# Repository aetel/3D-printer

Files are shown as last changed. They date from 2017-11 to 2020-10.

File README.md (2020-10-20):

Este repo contiene información, ficheros y archivos de configuración de las impresoras 3D de AETEL.  

# Federada
Nuestra Prusa i3 es un clon chino de la Prusa i3 MK2S.

# Genghis Khan
Prusa Mendel. [Clon 258 de Clone Wars](https://www.reprap.org/wiki/Clone_Wars:_El_imperio_de_los_clones/es#251-300). Piezas originales [entregadas por Obijuan](http://aetel.etsist.upm.es/2012/10/11/recogida-de-piezas-de-prusa-2-de-manos-de-obijuan/#more-1306).

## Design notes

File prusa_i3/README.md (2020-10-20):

# Federada
Federada es nuestra Prusa i3, un clon chino de la Prusa i3 MK2S.

Lleva dicho nombre en honor a Javier "Federado", gran impulsor de la impresión 3D y la filosofía RepRap dentro de la Asociación de Electrónica.

Algunas piezas han sido adaptadas para las vitaminas que se pueden conseguir en China. La electrónica es completamente distinta a la original de Prusa, SKR 1.3 de 32 bits; la cama caliente es la estándar RepRap.

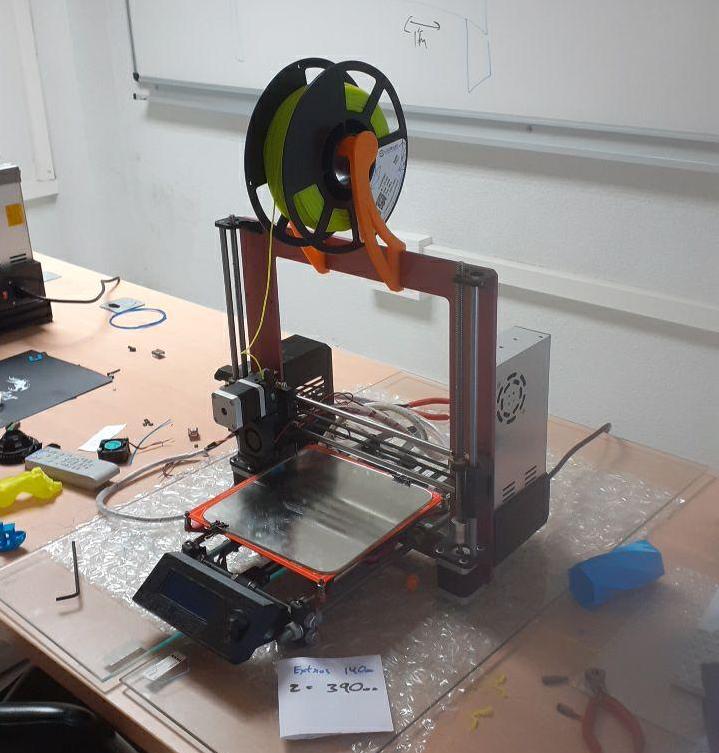
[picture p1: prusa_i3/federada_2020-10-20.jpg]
Federada


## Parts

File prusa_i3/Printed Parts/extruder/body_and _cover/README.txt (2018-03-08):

The 8mm sensor is approximately 21.5mm right and 9mm back from the nozzle.
The 12mm sensor is approximately 27mm right and 7mm back from the nozzle.
The 18mm sensor is approximately 32mm right and 3mm back from the nozzle.

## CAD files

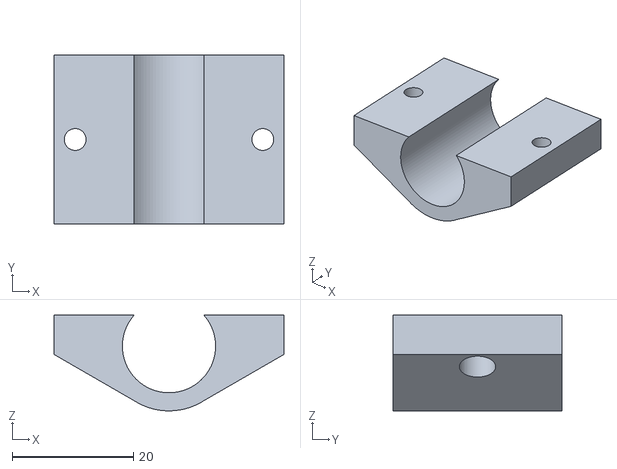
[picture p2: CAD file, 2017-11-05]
prusa_i3/Printed Parts/lmu88-holder-full.stl
38.0 x 27.9 x 15.8

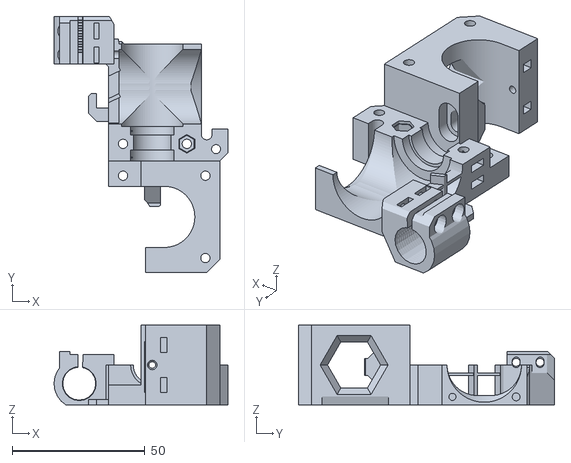
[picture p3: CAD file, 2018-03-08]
prusa_i3/Printed Parts/extruder/body_and _cover/extruder-bodyMK8S12.stl
65.5 x 96.5 x 30.0

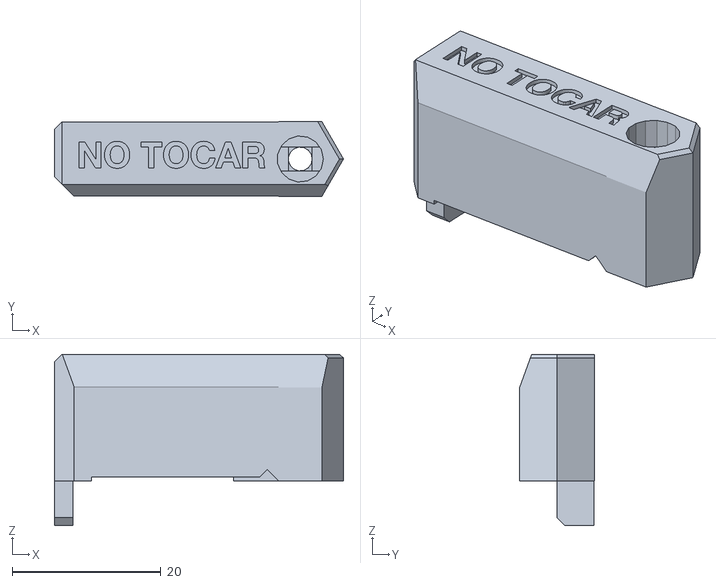
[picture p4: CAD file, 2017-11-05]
prusa_i3/Printed Parts/extruder/fan-nozzle.stl
38.8 x 10.0 x 23.0

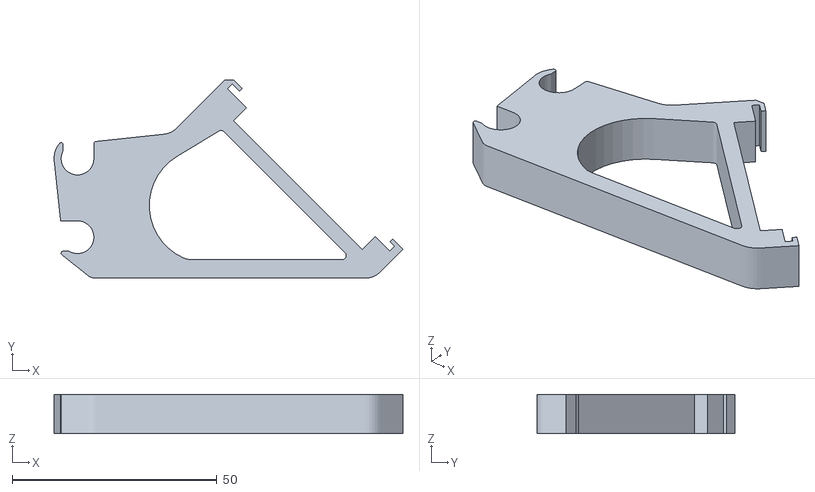
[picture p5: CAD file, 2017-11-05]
prusa_i3/Printed Parts/LCD/LCD-holder-A.STL
85.2 x 48.4 x 9.60

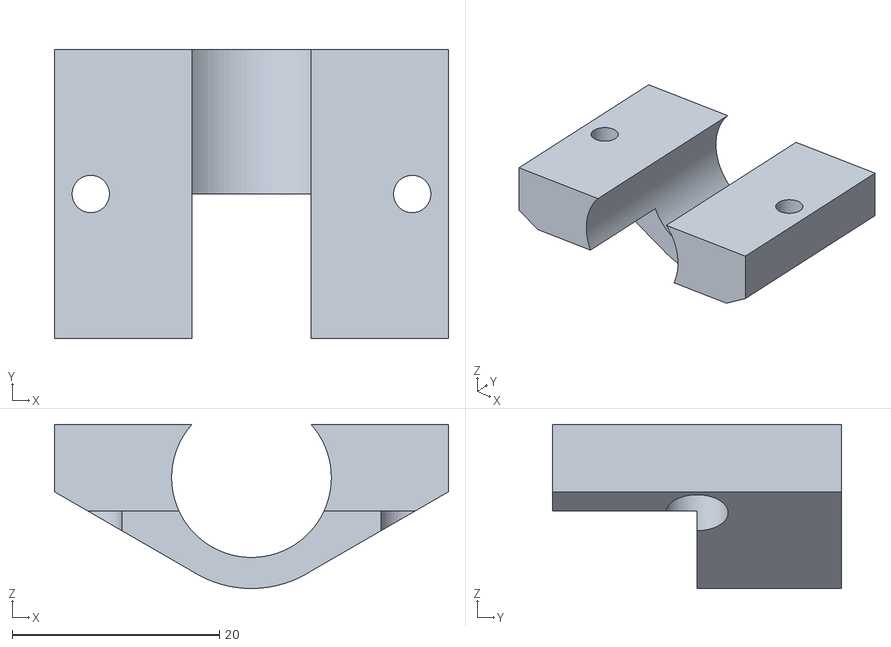
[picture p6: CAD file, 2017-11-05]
prusa_i3/Printed Parts/lmu88-holder-half.stl
38.0 x 27.9 x 15.8

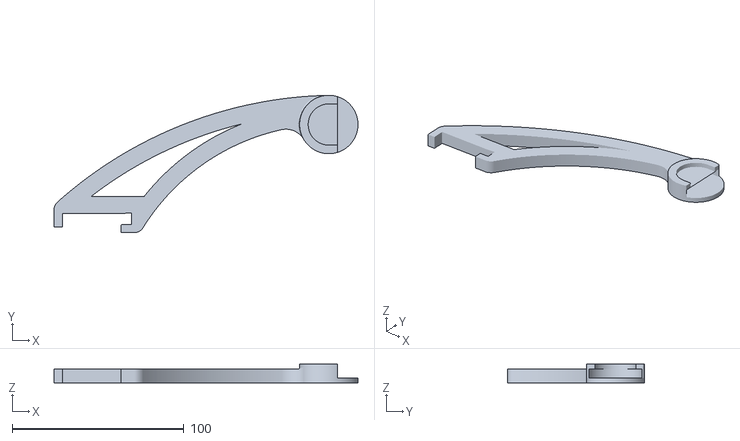
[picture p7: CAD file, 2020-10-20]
prusa_i3/Printed Parts/spool-holder/spool-holder-arm-L.stl
177.0 x 80.0 x 11.0

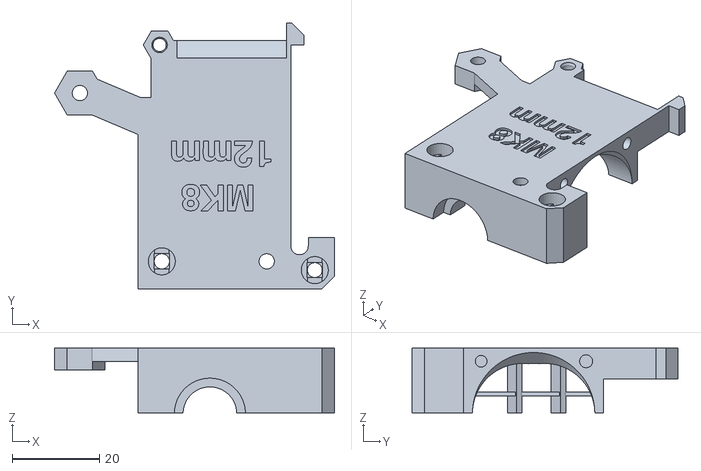
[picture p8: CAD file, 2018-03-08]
prusa_i3/Printed Parts/extruder/body_and _cover/extruder-coverMK8S12.stl
64.0 x 60.8 x 14.8

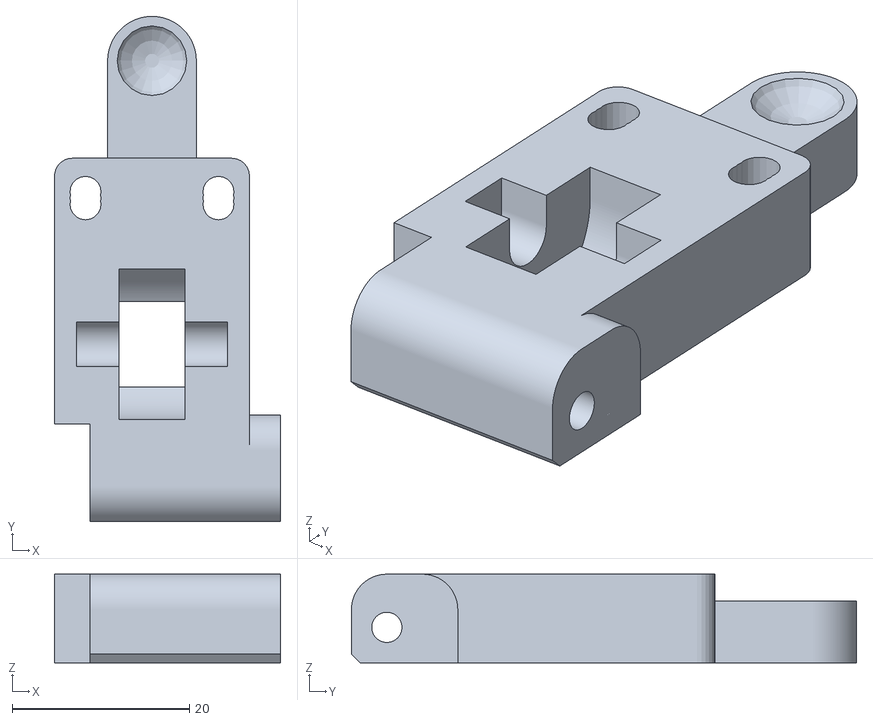
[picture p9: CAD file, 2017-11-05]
prusa_i3/Printed Parts/extruder/extruder-idler.stl
25.5 x 57.0 x 10.0

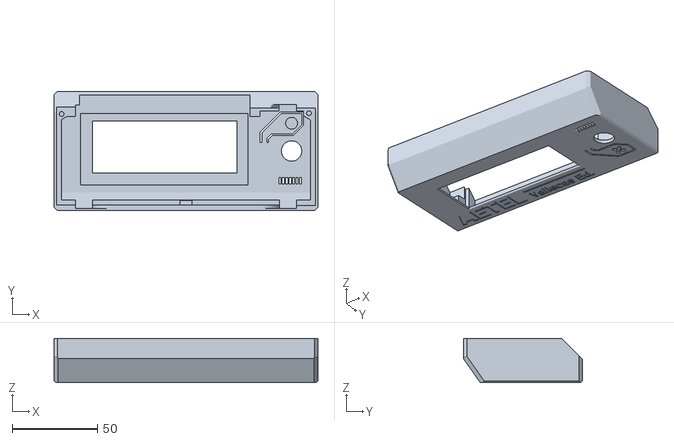
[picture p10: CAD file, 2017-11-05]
prusa_i3/Printed Parts/LCD/LCD-cover.stl
155.0 x 70.0 x 26.0

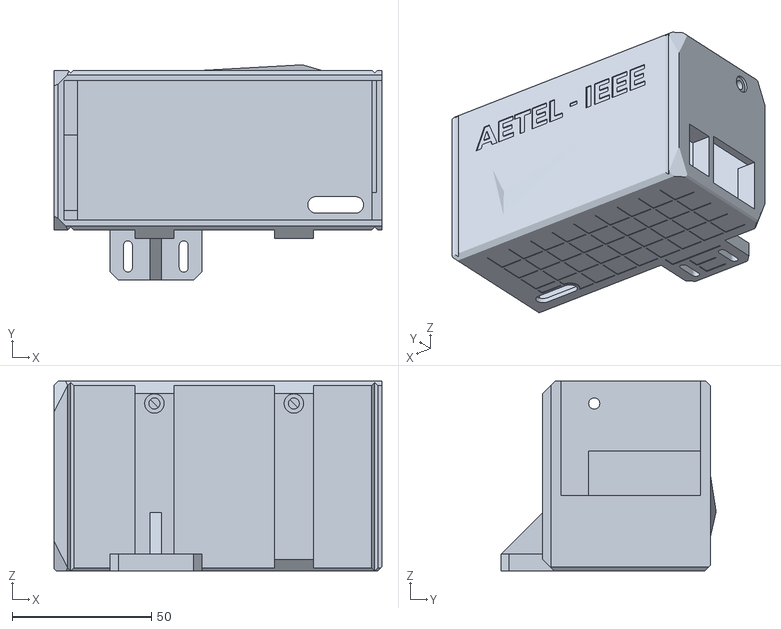
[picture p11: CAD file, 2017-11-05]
prusa_i3/Printed Parts/PSU-cover.stl
117.6 x 77.2 x 68.0

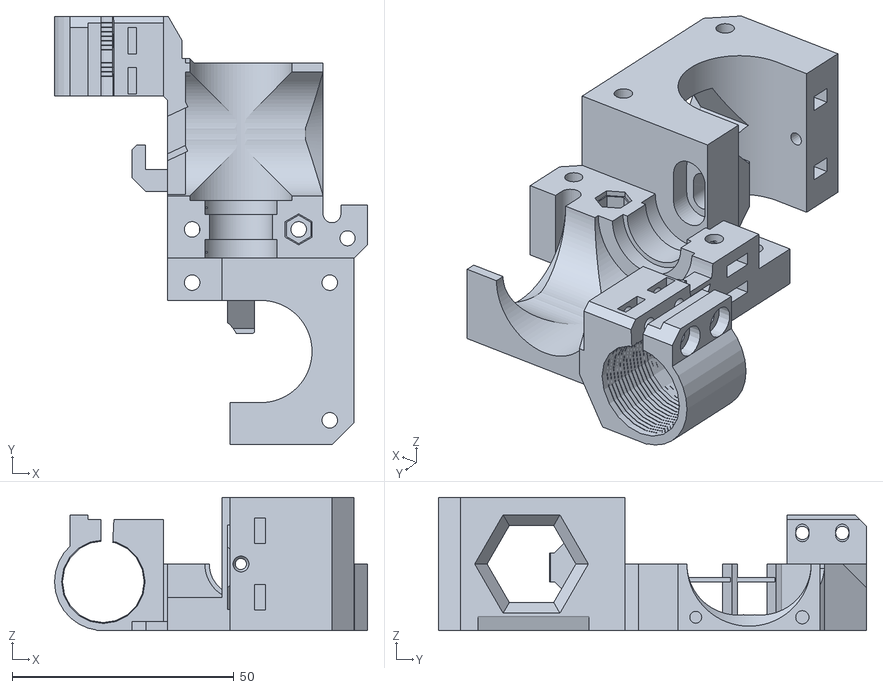
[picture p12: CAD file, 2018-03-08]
prusa_i3/Printed Parts/extruder/body_and _cover/extruder-bodyMK8S18.stl
70.5 x 96.5 x 30.0

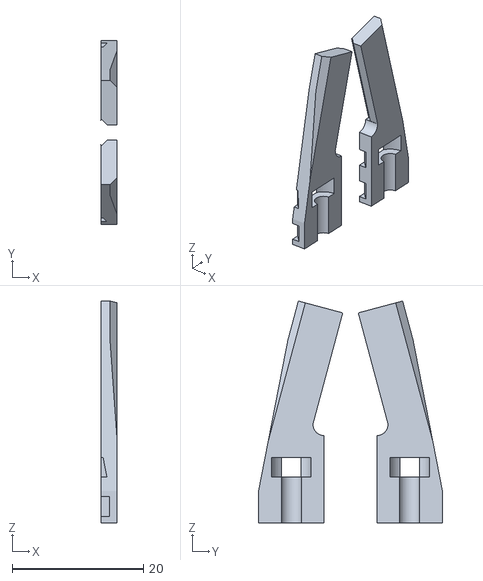
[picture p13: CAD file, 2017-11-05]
prusa_i3/Printed Parts/extruder/cable-holder.stl
2.50 x 28.0 x 33.8

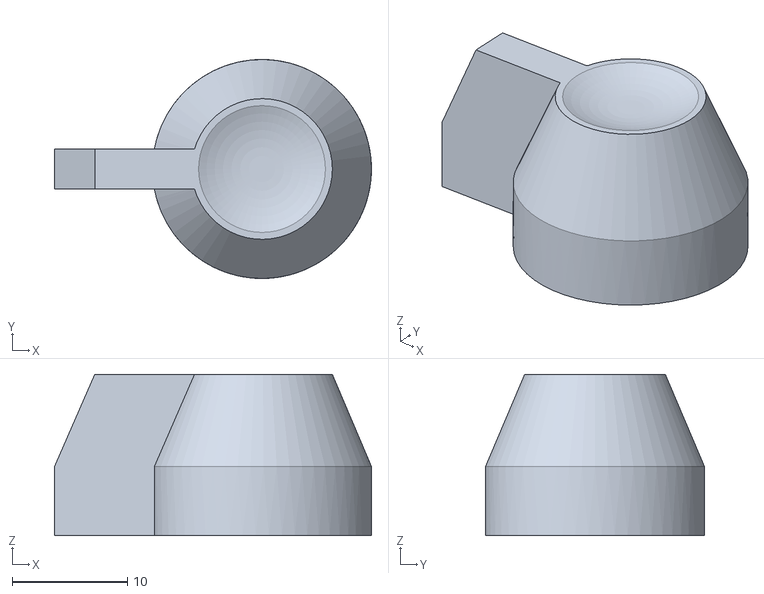
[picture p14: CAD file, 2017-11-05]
prusa_i3/Printed Parts/LCD/LCD-knob.stl
27.5 x 19.0 x 14.0

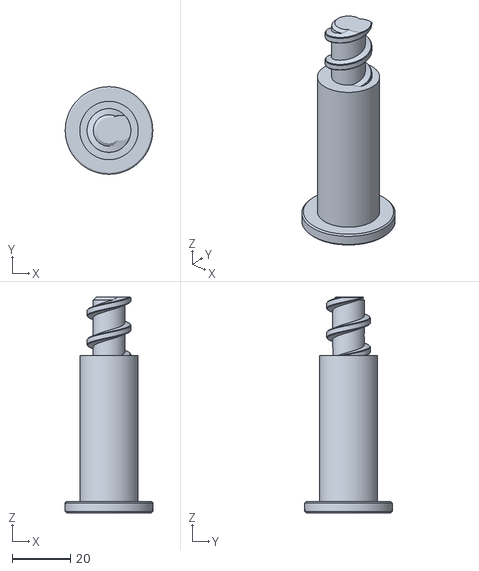
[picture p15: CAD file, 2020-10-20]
prusa_i3/Printed Parts/spool-holder/spool-holder-spindle-part1.stl
30.0 x 30.0 x 74.0

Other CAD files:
prusa_i3/Printed Parts/spool-holder/spool-holder-arm-R.stl
prusa_i3/Printed Parts/z-axis-bottom.stl
prusa_i3/Printed Parts/extruder/body_and _cover/extruder-coverMK8S18.stl
prusa_i3/Printed Parts/LCD/LCD-holder-B.STL
prusa_i3/Printed Parts/PSU-y-part.stl
prusa_i3/Printed Parts/aetel-box.stl
prusa_i3/Printed Parts/extruder/body_and _cover/extruder-bodyMK8S8.stl
prusa_i3/Printed Parts/extruder/body_and _cover/extruder-coverMK8S8.stl
prusa_i3/Printed Parts/spool-holder/spool-holder-spindle-part2.stl
prusa_i3/Printed Parts/x-carriage.stl
prusa_i3/Printed Parts/y-belt-holder.stl
prusa_i3/Printed Parts/y-corners.stl
prusa_i3/Printed Parts/y-distance.stl
prusa_i3/Printed Parts/y-idler.stl
prusa_i3/Printed Parts/y-motor.stl
prusa_i3/Printed Parts/z-axis-top.stl

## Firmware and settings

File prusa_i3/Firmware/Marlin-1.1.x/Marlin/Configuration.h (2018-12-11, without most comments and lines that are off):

#define CONFIGURATION_H
#define CONFIGURATION_H_VERSION 010107
#define STRING_CONFIG_H_AUTHOR "Ricardo Sanz" // Who made the changes.
#define SHOW_BOOTSCREEN
#define STRING_SPLASH_LINE1 SHORT_BUILD_VERSION // will be shown during bootup in line 1
#define STRING_SPLASH_LINE2 WEBSITE_URL         // will be shown during bootup in line 2
#define SERIAL_PORT 0
#define BAUDRATE 115200
  #define MOTHERBOARD BOARD_RAMPS_14_EFB
#define CUSTOM_MACHINE_NAME "AETEL MK2S"
#define EXTRUDERS 1
#define DEFAULT_NOMINAL_FILAMENT_DIA 1.75
#define POWER_SUPPLY 0
#define TEMP_SENSOR_0 1
#define TEMP_SENSOR_1 0
#define TEMP_SENSOR_2 0
#define TEMP_SENSOR_3 0
#define TEMP_SENSOR_4 0
#define TEMP_SENSOR_BED 1
#define DUMMY_THERMISTOR_998_VALUE 25
#define DUMMY_THERMISTOR_999_VALUE 100
#define MAX_REDUNDANT_TEMP_SENSOR_DIFF 10
#define TEMP_RESIDENCY_TIME 10  // (seconds)
#define TEMP_HYSTERESIS 3       // (degC) range of +/- temperatures considered "close" to the target one
#define TEMP_WINDOW     1       // (degC) Window around target to start the residency timer x degC early.
#define TEMP_BED_RESIDENCY_TIME 10  // (seconds)
#define TEMP_BED_HYSTERESIS 3       // (degC) range of +/- temperatures considered "close" to the target one
#define TEMP_BED_WINDOW     1       // (degC) Window around target to start the residency timer x degC early.
#define HEATER_0_MINTEMP 5
#define HEATER_1_MINTEMP 5
#define HEATER_2_MINTEMP 5
#define HEATER_3_MINTEMP 5
#define HEATER_4_MINTEMP 5
#define BED_MINTEMP 5
#define HEATER_0_MAXTEMP 245
#define HEATER_1_MAXTEMP 275
#define HEATER_2_MAXTEMP 275
#define HEATER_3_MAXTEMP 275
#define HEATER_4_MAXTEMP 275
#define BED_MAXTEMP 105
#define PIDTEMP
#define BANG_MAX 255     // Limits current to nozzle while in bang-bang mode; 255=full current
#define PID_MAX BANG_MAX // Limits current to nozzle while PID is active (see PID_FUNCTIONAL_RANGE below); 255=full current
#define PID_K1 0.95      // Smoothing factor within the PID
  #define PID_AUTOTUNE_MENU // Add PID Autotune to the LCD "Temperature" menu to run M303 and apply the result.
  #define PID_FUNCTIONAL_RANGE 10 // If the temperature difference between the target temperature and the actual temperature
  #define  DEFAULT_Kp 17.69
  #define  DEFAULT_Ki 1.48
  #define  DEFAULT_Kd 52.89
#define MAX_BED_POWER 255 // limits duty cycle to bed; 255=full current
#define PREVENT_COLD_EXTRUSION
#define EXTRUDE_MINTEMP 170
#define PREVENT_LENGTHY_EXTRUDE
#define EXTRUDE_MAXLENGTH 200
#define THERMAL_PROTECTION_HOTENDS // Enable thermal protection for all extruders
#define THERMAL_PROTECTION_BED     // Enable thermal protection for the heated bed
#define USE_XMIN_PLUG
#define USE_YMIN_PLUG
#define USE_ZMIN_PLUG
#define ENDSTOPPULLUPS // Comment this out (using // at the start of the line) to disable the endstop pullup resistors
#define X_MIN_ENDSTOP_INVERTING false // set to true to invert the logic of the endstop.
#define Y_MIN_ENDSTOP_INVERTING false // set to true to invert the logic of the endstop.
#define Z_MIN_ENDSTOP_INVERTING false // set to true to invert the logic of the endstop.
#define _ENDSTOP_INVERTING true // set to true to invert the logic of the endstop.
#define Y_MAX_ENDSTOP_INVERTING true // set to true to invert the logic of the endstop.
#define Z_MAX_ENDSTOP_INVERTING true // set to true to invert the logic of the endstop.
#define Z_MIN_PROBE_ENDSTOP_INVERTING false // set to true to invert the logic of the probe.
#define DEFAULT_AXIS_STEPS_PER_UNIT   { 160, 160, 800, 75.58413854}
#define DEFAULT_MAX_FEEDRATE          { 300, 300, 5, 8.4 }
#define DEFAULT_MAX_ACCELERATION      { 3000, 3000, 100, 10000 }
#define DEFAULT_ACCELERATION          3000    // X, Y, Z and E acceleration for printing moves
#define DEFAULT_RETRACT_ACCELERATION  3000    // E acceleration for retracts
#define DEFAULT_TRAVEL_ACCELERATION   3000    // X, Y, Z acceleration for travel (non printing) moves
#define DEFAULT_XJERK                 10.0
#define DEFAULT_YJERK                 10.0
#define DEFAULT_ZJERK                  0.3
#define DEFAULT_EJERK                  5.0
#define Z_MIN_PROBE_USES_Z_MIN_ENDSTOP_PIN
#define FIX_MOUNTED_PROBE
#define X_PROBE_OFFSET_FROM_EXTRUDER 32  // X offset: -left  +right  [of the nozzle]
#define Y_PROBE_OFFSET_FROM_EXTRUDER 3  // Y offset: -front +behind [the nozzle]
#define Z_PROBE_OFFSET_FROM_EXTRUDER 0   // Z offset: -below +above  [the nozzle]
#define XY_PROBE_SPEED 8000
#define Z_PROBE_SPEED_FAST HOMING_FEEDRATE_Z
#define Z_PROBE_SPEED_SLOW (Z_PROBE_SPEED_FAST / 2)
#define Z_CLEARANCE_DEPLOY_PROBE   10 // Z Clearance for Deploy/Stow
#define Z_CLEARANCE_BETWEEN_PROBES  5 // Z Clearance between probe points
#define Z_PROBE_OFFSET_RANGE_MIN -20
#define Z_PROBE_OFFSET_RANGE_MAX 20
#define X_ENABLE_ON 0
#define Y_ENABLE_ON 0
#define Z_ENABLE_ON 0
#define E_ENABLE_ON 0 // For all extruders
#define DISABLE_X false
#define DISABLE_Y false
#define DISABLE_Z false
#define DISABLE_E false // For all extruders
#define DISABLE_INACTIVE_EXTRUDER true // Keep only the active extruder enabled.
#define INVERT_X_DIR true
#define INVERT_Y_DIR false
#define INVERT_Z_DIR false
#define INVERT_E0_DIR false
#define INVERT_E1_DIR false
#define INVERT_E2_DIR false
#define INVERT_E3_DIR false
#define INVERT_E4_DIR false
#define X_HOME_DIR -1
#define Y_HOME_DIR -1
#define Z_HOME_DIR -1
#define X_BED_SIZE 215
#define Y_BED_SIZE 200
#define X_MIN_POS 0
#define Y_MIN_POS 0
#define Z_MIN_POS 0
#define X_MAX_POS X_BED_SIZE
#define Y_MAX_POS Y_BED_SIZE
#define Z_MAX_POS 200
#define MIN_SOFTWARE_ENDSTOPS
  #define MIN_SOFTWARE_ENDSTOP_X
  #define MIN_SOFTWARE_ENDSTOP_Y
  #define MIN_SOFTWARE_ENDSTOP_Z
#define MAX_SOFTWARE_ENDSTOPS
  #define MAX_SOFTWARE_ENDSTOP_X
  #define MAX_SOFTWARE_ENDSTOP_Y
  #define MAX_SOFTWARE_ENDSTOP_Z
#define AUTO_BED_LEVELING_BILINEAR
#define DEBUG_LEVELING_FEATURE
  #define ENABLE_LEVELING_FADE_HEIGHT
  #define SEGMENT_LEVELED_MOVES
  #define LEVELED_SEGMENT_LENGTH 5.0 // (mm) Length of all segments (except the last one)
  #define G26_MESH_VALIDATION   // Enable G26 mesh validation
    #define MESH_TEST_NOZZLE_SIZE     0.4   // (mm) Diameter of primary nozzle.
    #define MESH_TEST_LAYER_HEIGHT    0.2   // (mm) Default layer height for the G26 Mesh Validation Tool.
    #define MESH_TEST_HOTEND_TEMP   205.0   // (°C) Default nozzle temperature for the G26 Mesh Validation Tool.
    #define MESH_TEST_BED_TEMP       60.0   // (°C) Default bed temperature for the G26 Mesh Validation Tool.
  #define GRID_MAX_POINTS_X 3
  #define GRID_MAX_POINTS_Y GRID_MAX_POINTS_X
  #define LEFT_PROBE_BED_POSITION 32
  #define RIGHT_PROBE_BED_POSITION 190
  #define FRONT_PROBE_BED_POSITION 15+15
  #define BACK_PROBE_BED_POSITION 182
  #define MIN_PROBE_EDGE 10
#define MANUAL_X_HOME_POS -14
#define Z_SAFE_HOMING
  #define Z_SAFE_HOMING_X_POINT ((X_BED_SIZE) / 2)    // X point for Z homing when homing all axes (G28).
  #define Z_SAFE_HOMING_Y_POINT ((Y_BED_SIZE) / 2)    // Y point for Z homing when homing all axes (G28).
#define HOMING_FEEDRATE_XY (50*60)
#define HOMING_FEEDRATE_Z  (4*60)
#define EEPROM_SETTINGS // Enable for M500 and M501 commands
#define EEPROM_CHITCHAT   // Give feedback on EEPROM commands. Disable to save PROGMEM.
#define HOST_KEEPALIVE_FEATURE        // Disable this if your host doesn't like keepalive messages
#define DEFAULT_KEEPALIVE_INTERVAL 2  // Number of seconds between "busy" messages. Set with M113.
#define BUSY_WHILE_HEATING            // Some hosts require "busy" messages even during heating
#define PREHEAT_1_TEMP_HOTEND 180
#define PREHEAT_1_TEMP_BED     70
#define PREHEAT_1_FAN_SPEED     0 // Value from 0 to 255
#define PREHEAT_2_TEMP_HOTEND 240
#define PREHEAT_2_TEMP_BED    110
#define PREHEAT_2_FAN_SPEED     0 // Value from 0 to 255
#define PRINTJOB_TIMER_AUTOSTART
#define PRINTCOUNTER
#define LCD_LANGUAGE en
#define DISPLAY_CHARSET_HD44780 JAPANESE
#define SDSUPPORT
#define REPRAP_DISCOUNT_SMART_CONTROLLER
#define SOFT_PWM_SCALE 0
#define SERVO_DELAY { 300 }

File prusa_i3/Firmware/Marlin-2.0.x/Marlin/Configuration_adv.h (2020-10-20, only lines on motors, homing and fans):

#define X_MICROSTEPS    16
#define Y_MICROSTEPS    16
#define Z_MICROSTEPS    16
#define E0_MICROSTEPS    16
#define E0_AUTO_FAN_PIN -1
#define E1_AUTO_FAN_PIN -1
#define E2_AUTO_FAN_PIN -1
#define E3_AUTO_FAN_PIN -1
#define E4_AUTO_FAN_PIN -1
#define E5_AUTO_FAN_PIN -1
#define E6_AUTO_FAN_PIN -1
#define E7_AUTO_FAN_PIN -1
#define CHAMBER_AUTO_FAN_PIN -1
#define HOMING_BUMP_MM      { 5, 5, 2 }       // (mm) Backoff from endstops after first bump
#define HOMING_BUMP_DIVISOR { 2, 2, 4 }       // Re-Bump Speed Divisor (Divides the Homing Feedrate)
#define MICROSTEP_MODES { 16, 16, 16, 16, 16, 16 } // [1,2,4,8,16]

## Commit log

2017-11-05 First commit with i3 parts
    Added i3 parts and firmware
    [Configuration.h, Configuration_adv.h, LCD-cover.stl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]
2018-03-08 Added modified extruder files and firmware
    Now extruder can hold a 18mm sensor.
    Marlin Firmware is configured for our printer.
    [Configuration.h, Configuration_adv.h, extruder-bodyMK8S12.stl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]
2018-07-25 Add files via upload
    Sistema de autobed leveling configurado. Calibrado PID del extrusor y de la cama.
    [Configuration.h]
2018-10-04 Missing #endif
    [Configuration.h]
2018-12-11 El control de temperatura ahora usa un controlador bang-bang
    El MOSFET de potencia de la cama se quemó. Se instaló un relé para evitar el mismo fallo en el futuro y se cambió el firmware a un controlador bang-bang para evitar que esté cambiando todo el rato el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
    [Configuration.h]
2020-10-20 Added new Marlin 2.0 firmware
    [Configuration.h, Configuration_adv.h]
2020-10-20 Adds specific i3 README and picture of current status
2020-10-20 Adds spool holder STLs
    [spool-holder-arm-L.stl, spool-holder-arm-R.stl, spool-holder-spindle-part1.stl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]

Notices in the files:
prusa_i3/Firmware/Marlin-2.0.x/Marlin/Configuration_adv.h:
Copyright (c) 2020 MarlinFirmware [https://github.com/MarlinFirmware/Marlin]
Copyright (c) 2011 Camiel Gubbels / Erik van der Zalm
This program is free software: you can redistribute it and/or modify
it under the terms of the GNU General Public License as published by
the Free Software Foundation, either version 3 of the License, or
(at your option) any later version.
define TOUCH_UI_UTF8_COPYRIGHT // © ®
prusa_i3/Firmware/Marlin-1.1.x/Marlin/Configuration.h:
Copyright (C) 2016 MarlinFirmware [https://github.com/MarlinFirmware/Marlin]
